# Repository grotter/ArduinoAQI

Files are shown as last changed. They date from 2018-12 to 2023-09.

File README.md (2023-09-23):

# ArduinoAQI

This device continuously monitors atmospheric particulate matter. It sends sensor data to a registered ThingSpeak channel and displays realtime Air Quality Index [calculations](https://en.wikipedia.org/wiki/Air_quality_index#United_States). It was designed to be cheap and efficient.

## Hardware
* ESP8266 Arduino-compatible microcontroller. I‘m using a [WeMos D1 mini](https://www.wemos.cc/en/latest/d1/d1_mini.html), pins will need to be transposed for other controllers
* [Plantower PMS5003](https://cdn-shop.adafruit.com/product-files/3686/plantower-pms5003-manual_v2-3.pdf) laser particle concentration sensor
* [TM1637](http://dx.com/p/0-36-led-4-digit-display-module-for-arduino-black-blue-works-with-official-arduino-boards-254978) seven segment LED display module
* A momentary switch for resetting the wifi configuration

## Dependencies
* A minimally hacked version (included in this repo) of tzapu’s [WiFiManager](https://github.com/tzapu/WiFiManager)
* [Arduino_JSON](https://github.com/arduino-libraries/Arduino_JSON)
* fu-hsi‘s [library](https://github.com/fu-hsi/PMS) for Plantower PMS x003 family sensors
* bremme‘s [library](https://github.com/bremme/arduino-tm1637) for controlling TM1637 display modules
* mathwork‘s [ThingSpeak library](https://github.com/mathworks/thingspeak-arduino) – note: latest version is buggy, use [release v1.4.3](https://github.com/mathworks/thingspeak-arduino/releases/tag/1.4.3) 
* madleech‘s [Button library](https://github.com/madleech/Button)

## Configuration

ArduinoAQI uses ThingSpeak for both uploading sensor data and for reading configuration. You will need a [ThingSpeak](https://thingspeak.com/) account and least two channels: a registration channel to store configuration and a data channel to write sensor data to. The registration channel should have three fields:

1. Device MAC Address
2. Data Channel ID
3. Data Channel Write API Key

The data channel should have four fields:

1. PM 1.0 (µg/m³)
2. PM 2.5 (µg/m³)
3. PM 10.0 (µg/m³)
4. AQI

You will need to upload or import data into the registration channel, with one data point per device containing the desired data channel ID and corresponding Write API Key.

Copy `config.h` to `private/config.h` and fill in at least `THINGSPEAK_REGISTRY_CHANNEL_NUMBER` and `THINGSPEAK_REGISTRY_API_KEY` with the ID of the ThingSpeak registration channel ID and corresponding *Read* API Key.

You can use the shell command `addSensor.sh` to partially automate the creation and registration processes above.

## Usage

To setup wifi connectivity, the device will create an *ArduinoAQI Setup* access point when first run. Connect to this network with a phone or computer to set your wifi credentials.

The device powers up in spinup mode for an initial ten seconds. Set wifi mode to **off** by clicking the reset button during spinup. In wifi mode, the reset button will clear your network credentials and relaunch the configuration access point.

View detailed [setup instructions](SetupInstructions.md) for a new device.

## WeMos D1 mini Wiring Diagram
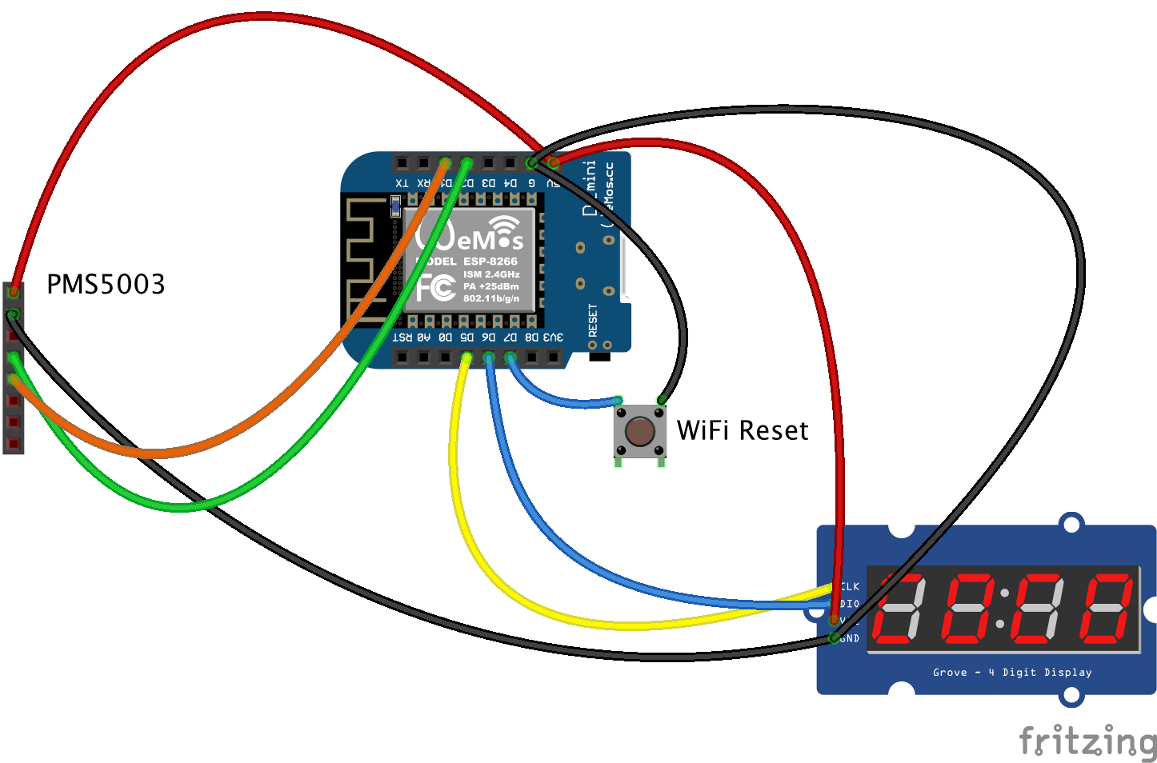
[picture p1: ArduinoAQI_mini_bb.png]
ArduinoAQI wiring diagram

Also tested with a [WeMos D1 R2](ArduinoAQI_bb.png) development board. Note: Pin labels on the D1 R2 fritzing component are wonky.

## JavaScript Chart

See [ChartAQI](https://github.com/grotter/ChartAQI) to view your sensor data and any optional PurpleAir sensors.

### 💨💨💨

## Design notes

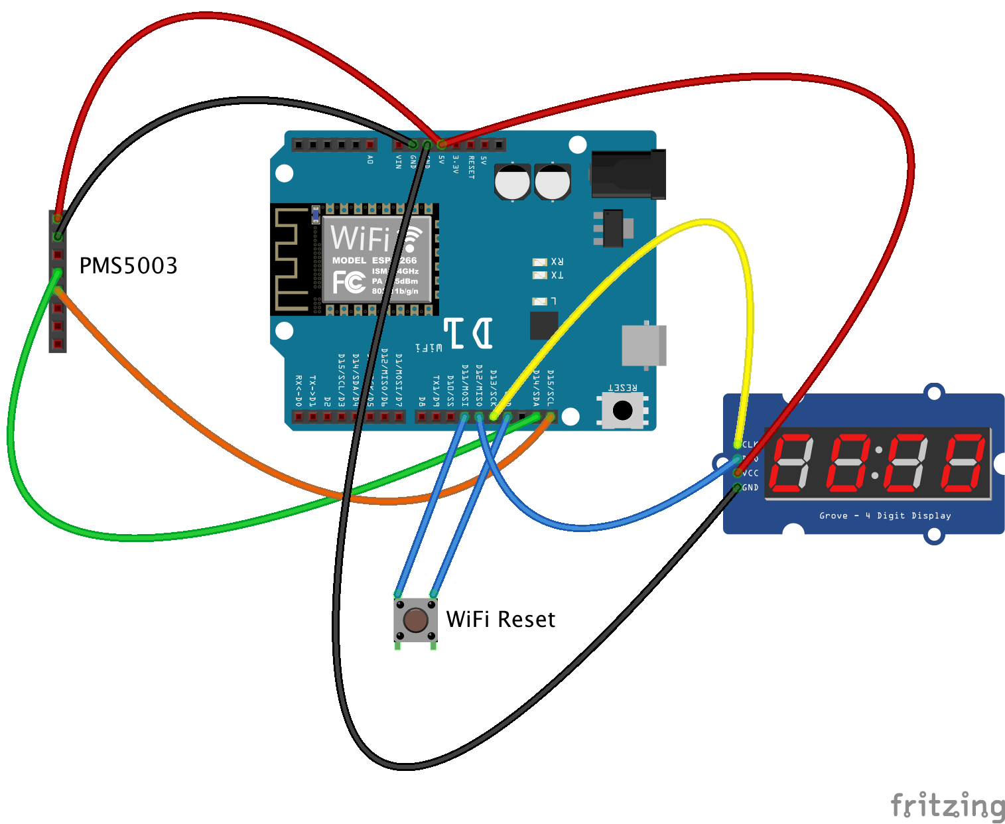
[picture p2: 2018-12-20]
ArduinoAQI_bb.png

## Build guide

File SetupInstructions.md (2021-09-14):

# ArduinoAQI new device setup

1. Place sensor in range of your wifi router
2. Connect sensor to power, wait about 30 seconds until display reads "conn"
3. The sensor should create a new wifi network *ArduinoAQI Setup*, connect to this network with your phone using the password `AP_PASSWORD`
4. Once your phone connects to the *ArduinoAQI Setup* network, you should get a configuration popup
5. Select your home wifi network from the dropdown and enter your password, then tap **Save**

If you entered the wrong password or need to change networks, push the silver button on the back of the sensor and it'll clear your settings and start over.

If you don't want to bother with wifi, unplug the sensor, then plug it back in. While it's doing its twirly spinup, push the silver button on the back and it'll switch to offline mode.

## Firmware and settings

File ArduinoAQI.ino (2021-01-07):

#include <SoftwareSerial.h>
#include <Button.h>
#include <PMS.h>
#include "SevenSegmentSnake.h"
#include "ArduinoAQIData.h"
#include "CalculateAQI.h"

static const uint16_t PMS_TIMEOUT_MS = 2000;

Button resetButton(PIN_RESET);
SevenSegmentSnake display(PIN_LED_CLK, PIN_LED_DIO);

SoftwareSerial pmsSerial(PIN_PMS_TX, PIN_PMS_RX);
PMS pms(pmsSerial);
PMS::DATA pmsData;

ArduinoAQIData data;
SensorData sensorData;
unsigned long lastDataSend = 0;
unsigned long lastSpinupStep = 0;
unsigned long spinupTimeStart = 0;
unsigned long programStartTime = 0;
bool isSpinningUp = true;
bool isWifiMode = true;

void setup() {
  Serial.begin(9600);
  pmsSerial.begin(9600);

  Serial.println("");
  Serial.println("ArduinoAQI");
  Serial.println("");

  // LED_BUILTIN on the WeMos D1 R2 is inverted
  pinMode(LED_BUILTIN, OUTPUT);
  digitalWrite(LED_BUILTIN, HIGH);

  // initialize display
  Serial.println("Starting in spinup mode…");
  display.begin();
  display.setBacklight(10);

  // check for saved wifi mode
  if (wasWifiModeDisabled()) {
    Serial.println("Wifi mode previously disabled. Skipping spinup…");
    stopSpinup();
    isWifiMode = false;
  }
  
  // initialize reset button
  resetButton.begin();

  // initialize sensor data
  resetSensorAverages();
  
  programStartTime = millis();
  spinupTimeStart = millis();
}

void resetSensorAverages() {
  sensorData = {
    PM_AE_UG_1_0: 0,
    PM_AE_UG_2_5: 0,
    PM_AE_UG_10_0: 0,
    AQI: 0,
    numReads: 0  
  };
}

void saveWifiMode() {
  byte disableWifi = isWifiMode ? 0 : 1;
  EEPROM.put(WIFI_VARIABLE_LENGTH * 2, disableWifi);
  EEPROM.commit();
}

bool wasWifiModeDisabled() {
  byte disableWifi = EEPROM.read(WIFI_VARIABLE_LENGTH * 2);
  return disableWifi == 1;
}

char *getNumberWithLeadingZeros(long num, char *buffer, int displayLength) {
  snprintf(buffer, ((size_t) displayLength) + 1, "%0*ld", displayLength, num);
  return buffer;
}

bool isTimeExceeded(unsigned long &startTime, unsigned long numMilliseconds) {
  unsigned long now = millis();

  if (startTime > now) {
    // clock overflowed
    startTime = 0;
    return false;
  }

  unsigned long diff = now - startTime;

  if (diff > numMilliseconds) {
    return true;
  } else {
    return false;
  }
}

void clearDisplay() {
  display.clear();
  display.print("----");
}

void setDisplay(const char *text) {
  display.clear();
  display.print(text);
}

void onAPMode(WiFiManager *myWiFiManager) {
  Serial.println("Creating access point: " + myWiFiManager->getConfigPortalSSID());
  setDisplay("conn");
}

void connectWifi() {
  clearDisplay();
  data.setAPCallback(onAPMode);
  data.begin();
}

void stopSpinup() {
  isSpinningUp = false;
  clearDisplay();
}

void onResetRelease() {
  // reset button switches behavior after spinup
  if (isSpinningUp) {
    Serial.println("Start without wifi.");
    isWifiMode = false;
    saveWifiMode();
    stopSpinup();
  } else {
    if (isWifiMode) {
      Serial.println("Reset wifi config…");
      data.resetWifi();
    } else {
      Serial.println("Switch to wifi mode. Attempt to connect…");
      isWifiMode = true;
      saveWifiMode();
      connectWifi();
    }
  }
}

unsigned long getRateLimitSeconds() {
  float messagesPerDay = MESSAGES_PER_YEAR / 365;
  float secondsPerDay = 60 * 60 * 24;
  float rateLimitSeconds = (secondsPerDay / messagesPerDay) * data.numRegisteredDevices;

  if (rateLimitSeconds < THINGSPEAK_RATE_LIMIT_SECONDS) {
    rateLimitSeconds = THINGSPEAK_RATE_LIMIT_SECONDS;
  }

  return ceil(rateLimitSeconds);
}

void processSensorData(bool trace) {
  if (pms.readUntil(pmsData, PMS_TIMEOUT_MS)) {
    if (trace) {
      Serial.print("PM 1.0 (ug/m3): ");
      Serial.println(pmsData.PM_AE_UG_1_0);
    
      Serial.print("PM 2.5 (ug/m3): ");
      Serial.println(pmsData.PM_AE_UG_2_5);
    
      Serial.print("PM 10.0 (ug/m3): ");
      Serial.println(pmsData.PM_AE_UG_10_0);
    
      Serial.println();
    }
    
    // calculate AQI
    float aqi = CalculateAQI::getPM25AQI(pmsData.PM_AE_UG_2_5);
    
    // display realtime unaveraged AQI
    char displayBuffer[DISPLAY_LENGTH + 1];
    setDisplay(getNumberWithLeadingZeros(round(aqi), displayBuffer, DISPLAY_LENGTH));
    
    if (!isWifiMode) return;

    // update for averaging
    CalculateAQI::updateSensorData(sensorData, pmsData, aqi);
    
    // wait a few secs
    unsigned long rateLimitSeconds = getRateLimitSeconds();
    if (!isTimeExceeded(lastDataSend, rateLimitSeconds * 1000)) return;
    
    // send averaged data to ThingSpeak
    SensorData averagedData = CalculateAQI::getAveragedData(sensorData);
    
    if (data.write(averagedData.PM_AE_UG_1_0, averagedData.PM_AE_UG_2_5, averagedData.PM_AE_UG_10_0, averagedData.AQI)) {
      Serial.println("Data written to ThingSpeak");
    } else {
      Serial.println("ThingSpeak write error!");
    }

    resetSensorAverages();
  
    lastDataSend = millis();
  } else {
    setDisplay("Err");
  }
}

void loop() {
  // hard restart every few hours
  if (isTimeExceeded(programStartTime, HOURS_TO_RESTART * 60 * 60 * 1000)) {
    data.disconnectAndRestart(false);
    return;
  }
  
  if (resetButton.released()) {
    onResetRelease();
  }
  
  if (isSpinningUp) {
    // process spinup animation
    if (isTimeExceeded(lastSpinupStep, 10)) {
      display.process();
      lastSpinupStep = millis();
    }
    
    if (isTimeExceeded(spinupTimeStart, SPINUP_SECONDS * 1000)) {
      stopSpinup();
      
      if (isWifiMode) {
        Serial.println("Spinup complete! Connect to wifi…");
        connectWifi();
      } else {
        Serial.println("Spinup complete! Skip wifi…");
      }
    }

    return;
  }

  if (data.isConnected()) {
    digitalWrite(LED_BUILTIN, LOW);
  } else {
    digitalWrite(LED_BUILTIN, HIGH);
  }

  processSensorData(true);
}

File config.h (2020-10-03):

#define ACCESS_POINT "ArduinoAQI Setup"
#define ACCESS_POINT_PASSWORD NULL // non-NULL string of length 8-63 bytes sets a password to enable WPA2 encryption
#define THINGSPEAK_REGISTRY_CHANNEL_NUMBER 0
#define THINGSPEAK_REGISTRY_API_KEY ""
#define THINGSPEAK_DEFAULT_DATA_CHANNEL_NUMBER 0
#define THINGSPEAK_DEFAULT_DATA_WRITE_API_KEY ""
#define THINGSPEAK_RATE_LIMIT_SECONDS 120
#define DISPLAY_LENGTH 4
#define SPINUP_SECONDS 10
#define WIFI_VARIABLE_LENGTH 60
#define MAX_CONNECTION_ATTEMPTS 5
#define MAX_DISCONNECT_ATTEMPTS 10
#define HOURS_TO_RESTART 6
#define MESSAGES_PER_YEAR 3000000
#define PIN_LED_CLK 14 // SCK D5 on WeMos D1 R2
#define PIN_LED_DIO 12 // MISO D6 on WeMos D1 R2
#define PIN_RESET 13 // MOSI D7 on WeMos D1 R2
#define PIN_PMS_TX 5 // SCL D1 on WeMos D1 R2
#define PIN_PMS_RX 4 // SDA D2 on WeMos D1 R2

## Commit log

2018-12-10 better JSON error handling
    [ArduinoAQI.ino]
2018-12-10 better wifi error handling
    [ArduinoAQI.ino, WiFiManager.cpp, WiFiManager.h]
2018-12-11 specifying max connection attempts to prevent blocking
    [ArduinoAQI.ino]
2018-12-12 adding public isConnected method and configured LED to indicate status
2018-12-14 adding fritzing wiring diagram
    [ArduinoAQI.fzz]
2018-12-17 first pass at sensor integration
2018-12-17 adding PMS5003 to fritzing
    [ArduinoAQI.fzz]
2018-12-18 fix connection in progress hanging
    [ArduinoAQI.ino, WiFiManager.cpp]
2018-12-21 attempting to fix more wifi wonkiness
    [ArduinoAQIData.cpp, WiFiManager.cpp, WiFiManager.h]
2018-12-21 debugging ThingSpeak error codes
    [ArduinoAQIData.cpp]
2018-12-21 bumping up ThingSpeak rate limit (-301 errors)
    [config.h]
2018-12-21 decrease rate limit and attempt to reconnect wifi client on ThingSpeak error
    [ArduinoAQIData.cpp, config.h]
2018-12-26 removing sensor data print and resetting rate limit
    [ArduinoAQI.ino, config.h]
2018-12-26 tracing ThingSpeak error code earlier
    [ArduinoAQIData.cpp]
2018-12-28 an attempted fix to reset
    [ArduinoAQIData.cpp]
2018-12-28 wait for disconnect on reset
    [ArduinoAQIData.cpp]
2018-12-28 tracing sensor data
2018-12-28 better AP error handling
    [ArduinoAQIData.cpp]
2018-12-29 calculating rate limit per num registered devices
2018-12-30 sending averaged sensor data to ThingSpeak
2018-12-30 only update sensorData in wifi mode
2019-01-31 adding sample js chart
2020-09-26 rename HTTP_HEAD to avoid name conflict with ESP8266WiFi.h
    [WiFiManager.cpp]
2020-10-02 add "conn" and "err" states to display
    currently it's easy to get confused between the various states the device can be in wrt wifi disabled/connecting/AP-setup,
    which all display "----", so this adds "conn" to the display instead during the AP-setup mode. in addition, it's useful
    to be able to tell when the device can't read from the sensor, so a 2s timeout is added along with "err" on the display
    in case no valid data was read.
2020-10-02 fix a couple memory safety issues
    [ArduinoAQI.ino]
2020-10-02 add optional setup AP password
    motivation: typing a wifi password into the unencrypted setup landing page on the unencrypted setup-mode AP leaves the
    password in plaintext vulnerable to passive wifi monitoring. this commit allows setting a password enabling WPA2 for the
    setup-mode AP
2020-10-09 err code tweak and mini wiring diagram
    [ArduinoAQI_mini.fzz]
2020-10-12 mini wiring diagram tweak
    [ArduinoAQI_mini.fzz]
2020-10-12 adding sensor title to latest chart read UI
2020-10-30 tweaks to mini fritzing
    [ArduinoAQI_mini.fzz]
2021-01-23 shell script for creating channel and registration for new sensor
